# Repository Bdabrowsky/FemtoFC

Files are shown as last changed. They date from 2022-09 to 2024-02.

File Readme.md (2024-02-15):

# Hardware files for Open Source flight computer for small diameter rockets
## 17,5x50mm 
## For software, visit [Source Page]([https://github.com/Bdabrowsky/Clockwork_Banana](https://github.com/Bdabrowsky/Clockwork_Banana/tree/Clockwork_Banana_FemtoFC))
## All above hardware is made using funding from [Odkrywcy Diamentów](https://odkrywcydiamentow.com.pl/) grant program


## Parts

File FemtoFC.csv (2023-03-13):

Source: | C:\Users\Bdabrowski\Documents\GitHub\FemtoFC\FemtoFC.kicad_sch
Date: | 29.11.2022 20:14:57
Tool: | Eeschema (6.0.1)
Generator: | C:\Program Files\KiCad\6.0\bin\scripting\plugins/bom_csv_grouped_by_value_with_fp.py
Component Count: | 63
Ref | Qnty | Value | Cmp name | Footprint | Description | Vendor
BZ1, | 1 | Buzzer | Buzzer | Buzzer_Beeper:Buzzer_Murata_PKMCS0909E | Buzzer, polarized
C1, C4, C6, C7, C8, C9, C10, C13, | 8 | 100nF | C | Capacitor_SMD:C_0603_1608Metric_Pad1.08x0.95mm_HandSolder | Unpolarized capacitor
C2, C3, C5, | 3 | 10uF | C | Capacitor_SMD:C_0603_1608Metric_Pad1.08x0.95mm_HandSolder | Unpolarized capacitor
C11, C12, | 2 | 22pF | C | Capacitor_SMD:C_0603_1608Metric_Pad1.08x0.95mm_HandSolder | Unpolarized capacitor
D1, D2, | 2 | G | LED | LED_SMD:LED_0603_1608Metric | Light emitting diode
D3, D4, | 2 | D_Schottky | D_Schottky | Diode_SMD:D_SOD-123 | Schottky diode
D5, D6, | 2 | LED | LED | LED_SMD:LED_0603_1608Metric_Pad1.05x0.95mm_HandSolder | Light emitting diode
F1, F2, | 2 | Polyfuse | Polyfuse | Fuse:Fuse_1206_3216Metric_Pad1.42x1.75mm_HandSolder | Resettable fuse, polymeric positive temperature coefficient
FB1, | 1 | FerriteBead_Small | FerriteBead_Small | Resistor_SMD:R_0805_2012Metric | Ferrite bead, small symbol
J1, | 1 | Power in | Screw_Terminal_01x02 | Connector_PinHeader_2.54mm:PinHeader_1x02_P2.54mm_Vertical | Generic screw terminal, single row, 01x02, script generated (kicad-library-utils/schlib/autogen/connector/)
J2, | 1 | Conn_01x02_Male | Conn_01x02_Male | Connector_PinHeader_2.54mm:PinHeader_1x02_P2.54mm_Vertical | Generic connector, single row, 01x02, script generated (kicad-library-utils/schlib/autogen/connector/)
J3, | 1 | Micro_SD_Card | Micro_SD_Card | Connector_Card:microSD_HC_Molex_104031-0811 | Micro SD Card Socket
J4, | 1 | Pyro 2 | Screw_Terminal_01x02 | TerminalBlock_4Ucon:TerminalBlock_4Ucon_1x02_P3.50mm_Vertical | Generic screw terminal, single row, 01x02, script generated (kicad-library-utils/schlib/autogen/connector/)
J5, | 1 | Pyro 1 | Screw_Terminal_01x02 | TerminalBlock_4Ucon:TerminalBlock_4Ucon_1x02_P3.50mm_Vertical | Generic screw terminal, single row, 01x02, script generated (kicad-library-utils/schlib/autogen/connector/)
JP1, | 1 | SolderJumper_2_Open | SolderJumper_2_Open | Jumper:SolderJumper-2_P1.3mm_Open_RoundedPad1.0x1.5mm | Solder Jumper, 2-pole, open
JP2, | 1 | SolderJumper_3_Open | SolderJumper_3_Open | Jumper:SolderJumper-3_P1.3mm_Open_RoundedPad1.0x1.5mm | Solder Jumper, 3-pole, open
P1, | 1 | USB_C_Plug_USB2.0 | USB_C_Plug_USB2.0 | Connector_USB:USB_C_Receptacle_JAE_DX07S016JA1R1500 | USB 2.0-only Type-C Plug connector
Q1, | 1 | FDS9926A | FDS9926A | Package_SO:SOIC-8_3.9x4.9mm_P1.27mm | 6.5A Id, 20V Vds, Dual N-Channel MOSFET, 30mOhm Ron, SO-8
Q2, | 1 | FDS4953 | FDS4953 | Package_SO:SOIC-8_3.9x4.9mm_P1.27mm
Q3, | 1 | NDT3055L | NDT3055L | Package_TO_SOT_SMD:TSOT-23_HandSoldering | 4A Id, 60V Vds, N-Channel Logic Level Enhancement Mode MOSFET, SOT-223
R1, | 1 | 22k | R | Resistor_SMD:R_0603_1608Metric_Pad0.98x0.95mm_HandSolder | Resistor
R2, R6, R10, R11, R12, R13, R16, R17, | 8 | 10k | R | Resistor_SMD:R_0603_1608Metric_Pad0.98x0.95mm_HandSolder | Resistor
R3, R4, R5, R7, R8, R9, R14, R15, | 8 | 100k | R | Resistor_SMD:R_0603_1608Metric_Pad0.98x0.95mm_HandSolder | Resistor
TP1, TP2, TP3, TP4, TP5, | 5 | TestPoint | TestPoint | TestPoint:TestPoint_Pad_D1.0mm | test point
U1, | 1 | USBLC6-2SC6 | USBLC6-2SC6 | Package_TO_SOT_SMD:SOT-23-6 | Very low capacitance ESD protection diode, 2 data-line, SOT-23-6
U2, | 1 | 3.3v REG | AMS1117-3.3 | Package_TO_SOT_SMD:SOT-223-3_TabPin2 | 1A Low Dropout regulator, positive, 3.3V fixed output, SOT-223
U3, | 1 | ATSAMD21G18A-M | ATSAMD21G18A-M | Package_DFN_QFN:QFN-48-1EP_7x7mm_P0.5mm_EP5.15x5.15mm | SAM D21 Microchip SMART ARM-based Flash MCU, 48Mhz, 256K Flash, 32K SRAM, QFN-48
U4, | 1 | W25Q128JVS | W25Q128JVS | Package_SON:WSON-8-1EP_6x5mm_P1.27mm_EP3.4x4.3mm | 128Mb Serial Flash Memory, Standard/Dual/Quad SPI, SOIC-8
U5, | 1 | LSM6DS3 | LSM6DS3 | Package_LGA:LGA-14_3x2.5mm_P0.5mm_LayoutBorder3x4y | I2C/SPI, iNEMO inertial module: always-on 3D accelerometer and 3D gyroscope
U6, | 1 | BMP280 | BMP280 | Package_LGA:Bosch_LGA-8_2x2.5mm_P0.65mm_ClockwisePinNumbering | Absolute Barometric Pressure Sensor, LGA-8
Y1, | 1 | Crystal | Crystal | Crystal:Crystal_SMD_3215-2Pin_3.2x1.5mm | Two pin crystal

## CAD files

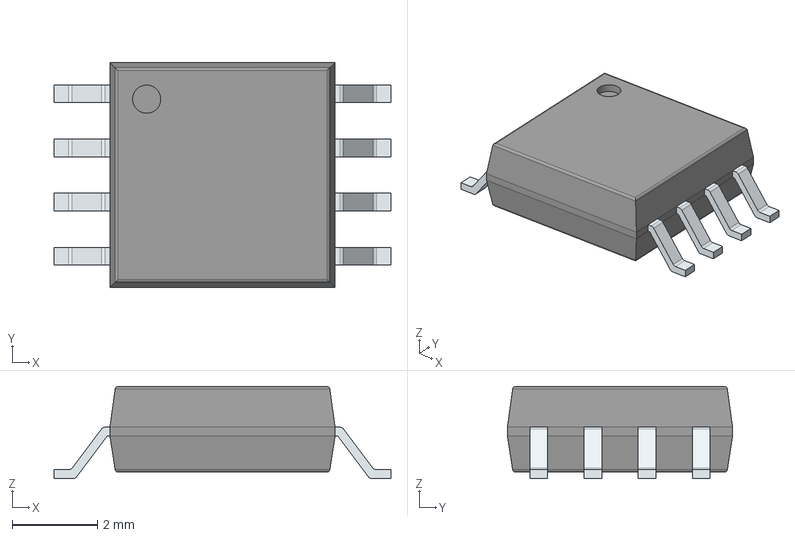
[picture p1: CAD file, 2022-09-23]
3D models/W25Q128JVSIM.stp
7.90 x 5.28 x 2.16 mm
PinsArrayLR

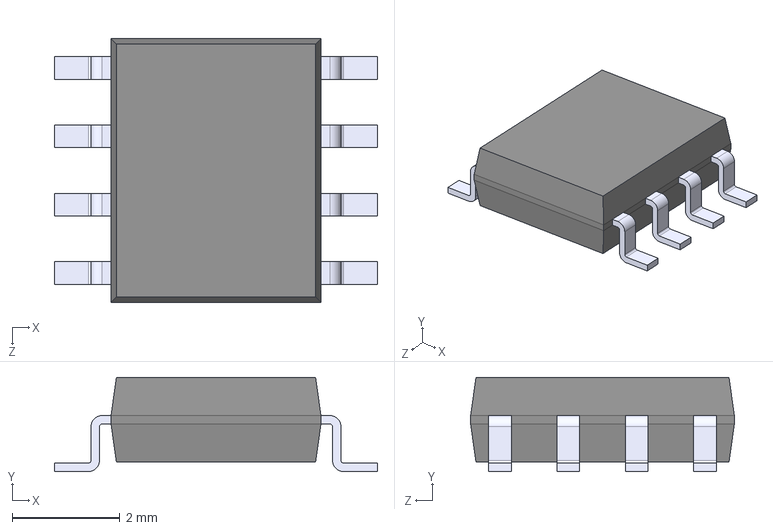
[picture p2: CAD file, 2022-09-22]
FDS4953/FDS4953.step
6.00 x 1.75 x 4.90 mm

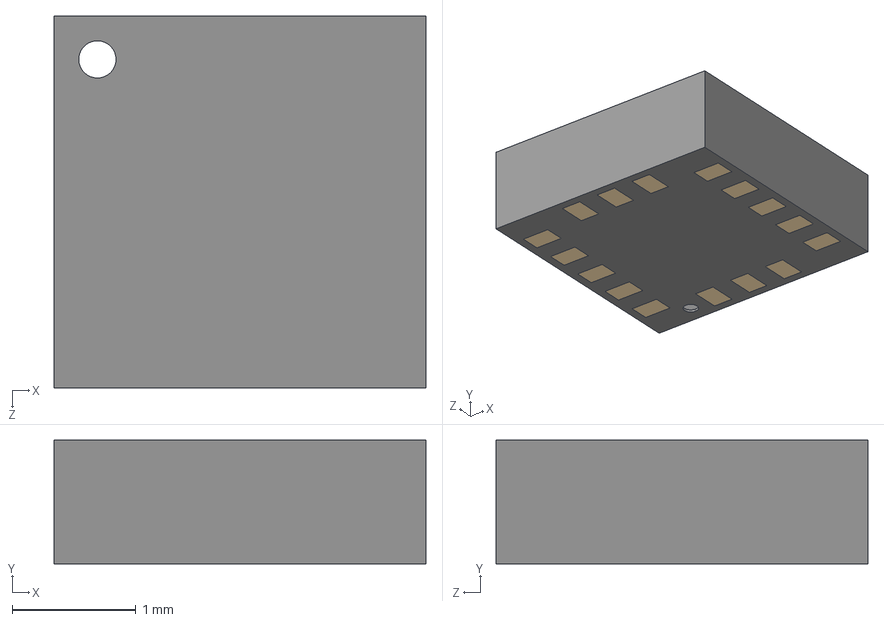
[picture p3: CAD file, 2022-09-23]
3D models/LSM6DS0.STEP
3.00 x 1.00 x 3.00 mm

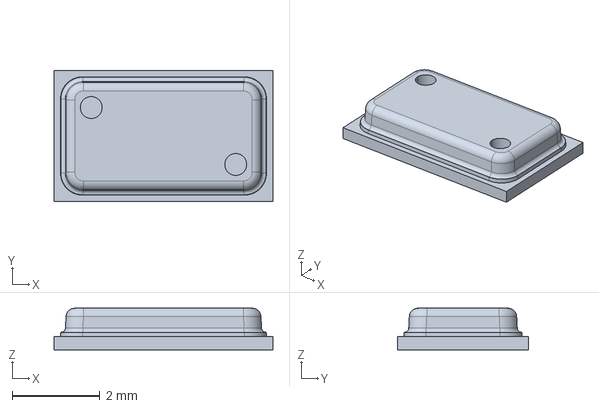
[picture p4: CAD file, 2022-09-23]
3D models/MS560702BA03-50.step
5.00 x 3.00 x 0.95 mm

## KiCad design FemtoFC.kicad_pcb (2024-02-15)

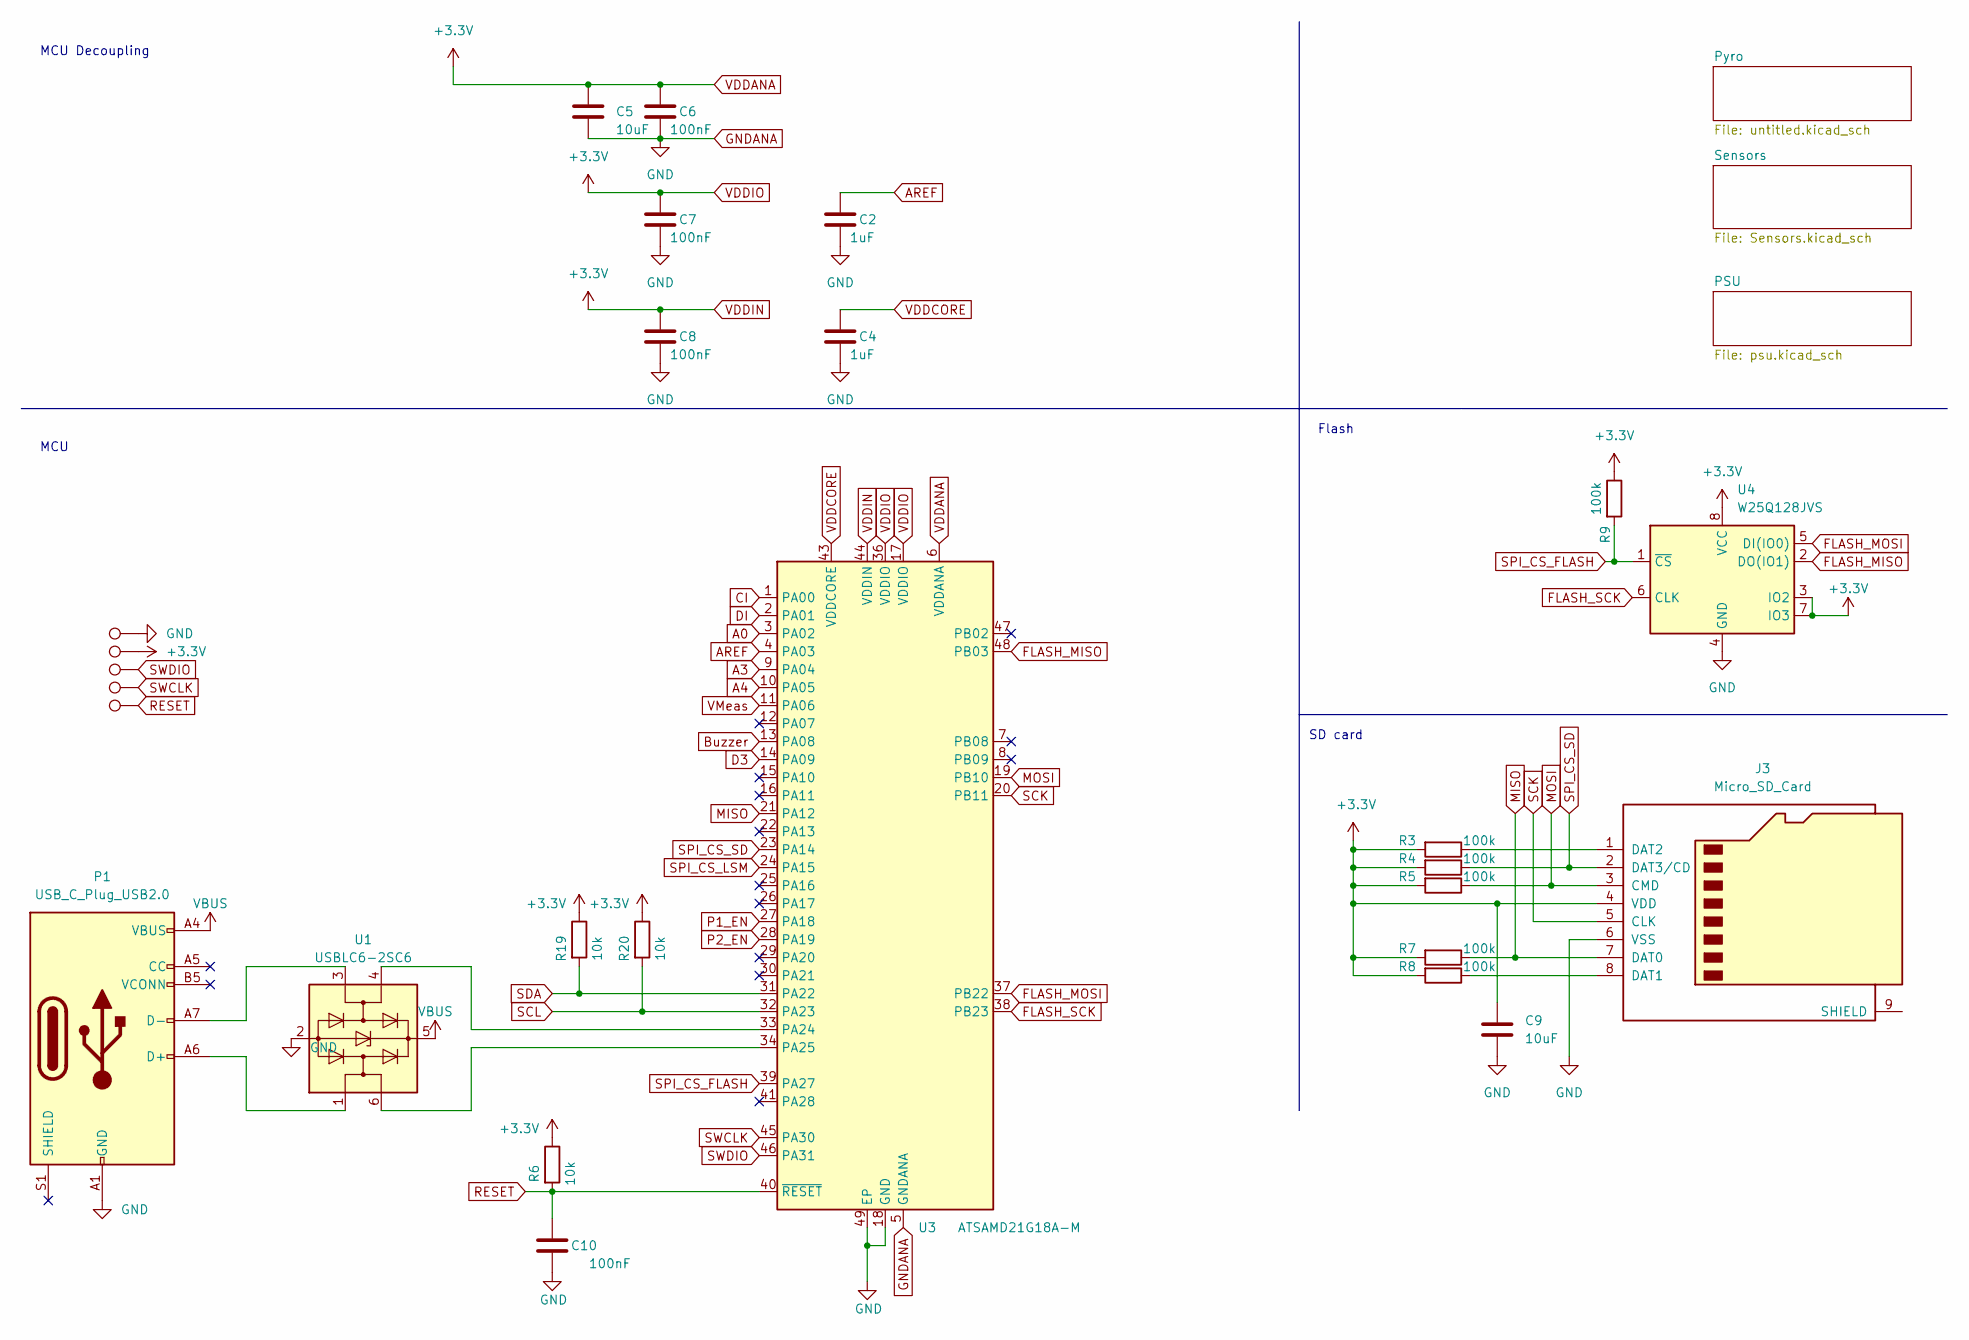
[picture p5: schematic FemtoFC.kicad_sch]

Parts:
C2, C4: 1uF; C_0402_1005Metric_Pad0.74x0.62mm_HandSolder
C5, C9: 10uF; C_0402_1005Metric_Pad0.74x0.62mm_HandSolder
C6, C7, C8, C10: 100nF; C_0402_1005Metric_Pad0.74x0.62mm_HandSolder
J3: Micro_SD_Card; microSD_HC_Molex_104031-0811
P1: USB_C_Plug_USB2.0; USB_C_Receptacle_JAE_DX07S016JA1R1500
R3, R4, R5, R7, R8, R9: 100k; R_0402_1005Metric_Pad0.72x0.64mm_HandSolder
R6, R19, R20: 10k; R_0402_1005Metric_Pad0.72x0.64mm_HandSolder
TP1, TP2, TP3, TP4, TP5: TestPoint; TestPoint_Pad_D1.0mm
U1: USBLC6-2SC6; SOT-23-6
U3: ATSAMD21G18A-M; QFN-48-1EP_7x7mm_P0.5mm_EP5.15x5.15mm
U4: W25Q128JVS; WSON-8-1EP_6x5mm_P1.27mm_EP3.4x4.3mm

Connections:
A0: U3.3 (PA02)
A3: U3.9 (PA04)
A4: U3.10 (PA05)
AREF: C2.1, U3.4 (PA03)
Buzzer: U3.13 (PA08); also elsewhere on the board
CI: U3.1 (PA00); also elsewhere on the board
D3: U3.14 (PA09)
DI: U3.2 (PA01); also elsewhere on the board
FLASH_MISO: U3.48 (PB03), U4.2 (DO(IO1))
FLASH_MOSI: U3.37 (PB22), U4.5 (DI(IO0))
FLASH_SCK: U3.38 (PB23), U4.6 (CLK)
GNDANA: C2.2, C4.2, C5.2, C6.2, C7.2, C8.2, C9.2, C10.2, J3.6 (VSS), P1.A1 (GND), P1.A12 (GND), P1.B1 (GND), P1.B12 (GND), TP1.1, U1.2 (GND), U3.5 (GNDANA), U3.18 (GND), U3.35 (GND), U3.42 (GND), U3.49 (EP), U4.4 (GND); also elsewhere on the board
MISO: J3.7 (DAT0), R7.1, U3.21 (PA12); also elsewhere on the board
MOSI: J3.3 (CMD), R5.1, U3.19 (PB10); also elsewhere on the board
unnamed: J3.1 (DAT2), R3.1
unnamed: J3.8 (DAT1), R8.1
unnamed: P1.A6 (D+), U1.1 (I/O1)
unnamed: P1.A7 (D-), U1.3 (I/O2)
unnamed: U1.4 (I/O2), U3.33 (PA24)
unnamed: U1.6 (I/O1), U3.34 (PA25)
P1_EN: U3.27 (PA18); also elsewhere on the board
P2_EN: U3.28 (PA19); also elsewhere on the board
RESET: C10.1, R6.2, TP5.1, U3.40 (~RESET)
SCK: J3.5 (CLK), U3.20 (PB11); also elsewhere on the board
SCL: R20.2, U3.32 (PA23); also elsewhere on the board
SDA: R19.2, U3.31 (PA22); also elsewhere on the board
SPI_CS_FLASH: R9.2, U3.39 (PA27), U4.1 (~CS)
SPI_CS_LSM: U3.24 (PA15); also elsewhere on the board
SPI_CS_SD: J3.2 (DAT3/CD), R4.1, U3.23 (PA14)
SWCLK: TP4.1, U3.45 (PA30)
SWDIO: TP3.1, U3.46 (PA31)
VBUS: P1.A4 (VBUS), P1.A9 (VBUS), P1.B4 (VBUS), P1.B9 (VBUS), U1.5 (VBUS); also elsewhere on the board
VDDANA: C5.1, C6.1, C7.1, C8.1, C9.1, J3.4 (VDD), R3.2, R4.2, R5.2, R6.1, R7.2, R8.2, R9.1, R19.1, R20.1, TP2.1, U3.6 (VDDANA), U3.17 (VDDIO), U3.36 (VDDIO), U3.44 (VDDIN), U4.3 (IO2), U4.7 (IO3), U4.8 (VCC); also elsewhere on the board
VDDCORE: C4.1, U3.43 (VDDCORE)
VMeas: U3.11 (PA06)

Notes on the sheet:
SD card
MCU
Flash
MCU Decoupling

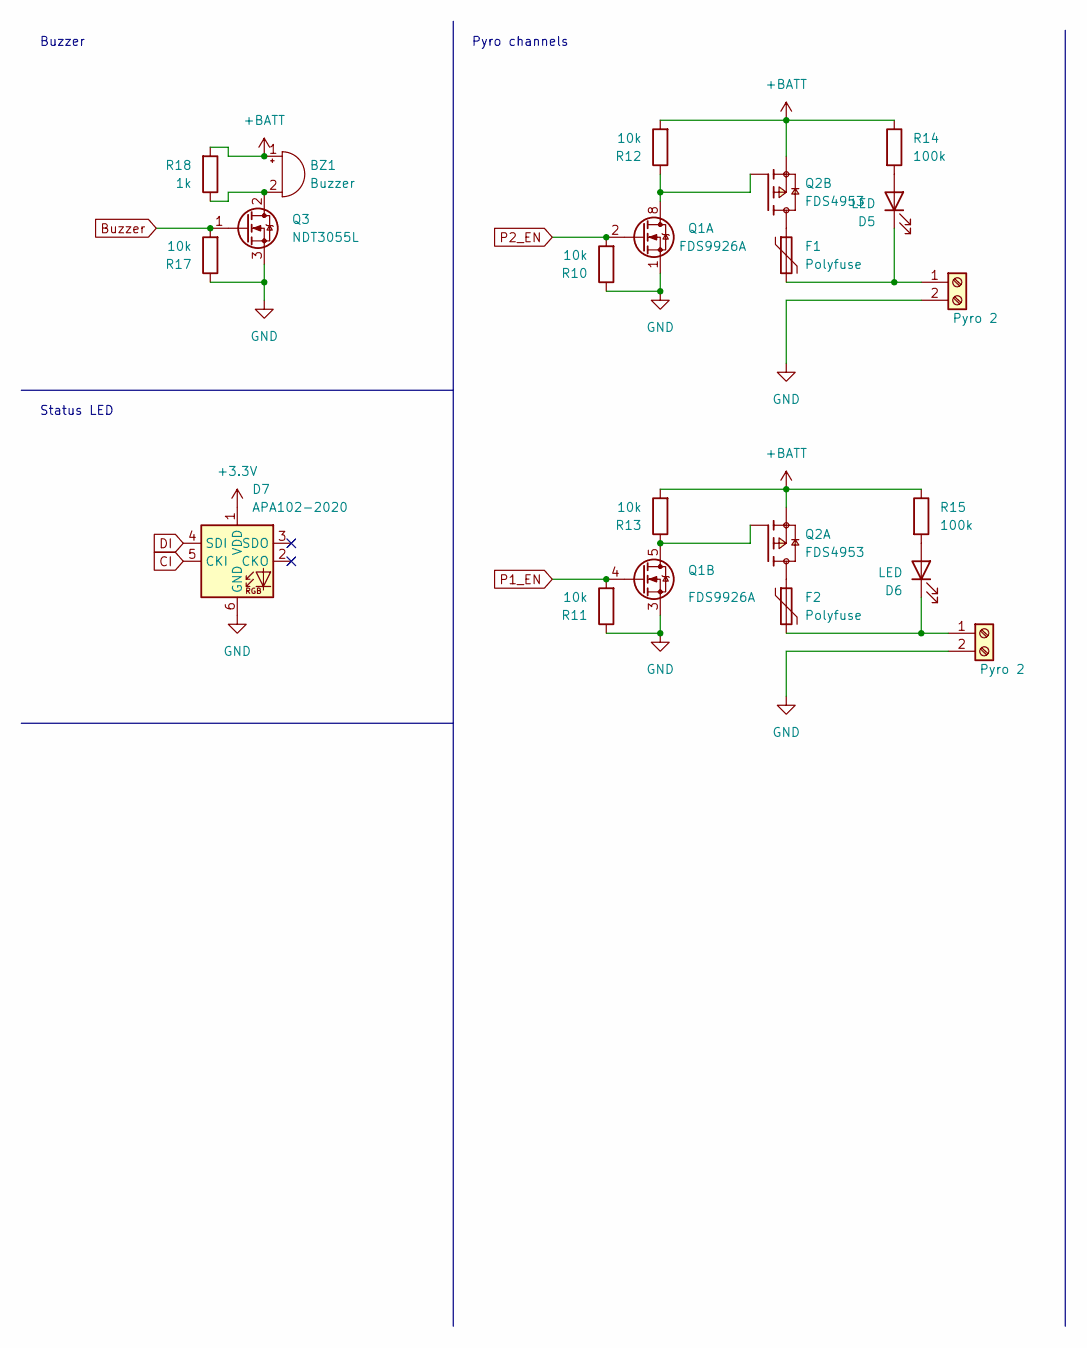
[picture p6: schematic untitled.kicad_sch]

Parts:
BZ1: Buzzer; Buzzer_Murata_PKMCS0909E
D5, D6: LED; LED_0603_1608Metric_Pad1.05x0.95mm_HandSolder
D7: APA102-2020; LED-APA102-2020
F1, F2: Polyfuse; Fuse_1206_3216Metric_Pad1.42x1.75mm_HandSolder
J4, J5: Pyro 2; TerminalBlock_Phoenix_MPT-0,5-2-2.54_1x02_P2.54mm_Horizontal
Q1: FDS9926A; SOIC-8_3.9x4.9mm_P1.27mm
Q2: FDS4953; SOIC-8_3.9x4.9mm_P1.27mm
Q3: NDT3055L; TSOT-23
R10, R11, R12, R13, R17: 10k; R_0402_1005Metric_Pad0.72x0.64mm_HandSolder
R14, R15: 100k; R_0402_1005Metric_Pad0.72x0.64mm_HandSolder
R18: 1k; R_0402_1005Metric_Pad0.72x0.64mm_HandSolder

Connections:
+BATT: BZ1.1 (-), Q2.1, Q2.3, R12.2, R13.2, R14.1, R15.1, R18.2; also elsewhere on the board
Buzzer: Q3.1 (G), R17.2; also elsewhere on the board
CI: D7.5 (CKI); also elsewhere on the board
DI: D7.4 (SDI); also elsewhere on the board
GNDANA: D7.6 (GND), J4.2, J5.2, Q1.1 (S1), Q1.3 (S2), Q3.3 (S), R10.1, R11.1, R17.1; also elsewhere on the board
unnamed: BZ1.2 (+), Q3.2 (D), R18.1
unnamed: D5.1 (K), F1.2, J4.1
unnamed: D5.2 (A), R14.2
unnamed: D6.1 (K), F2.2, J5.1
unnamed: D6.2 (A), R15.2
unnamed: F1.1, Q2.7, Q2.8
unnamed: F2.1, Q2.5, Q2.6
unnamed: Q1.5 (D2), Q1.6 (D2), Q2.4, R13.1
unnamed: Q1.7 (D1), Q1.8 (D1), Q2.2, R12.1
P1_EN: Q1.4 (G2), R11.2; also elsewhere on the board
P2_EN: Q1.2 (G1), R10.2; also elsewhere on the board
VDDANA: D7.1 (VDD); also elsewhere on the board

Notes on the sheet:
Buzzer
Status LED
Pyro channels

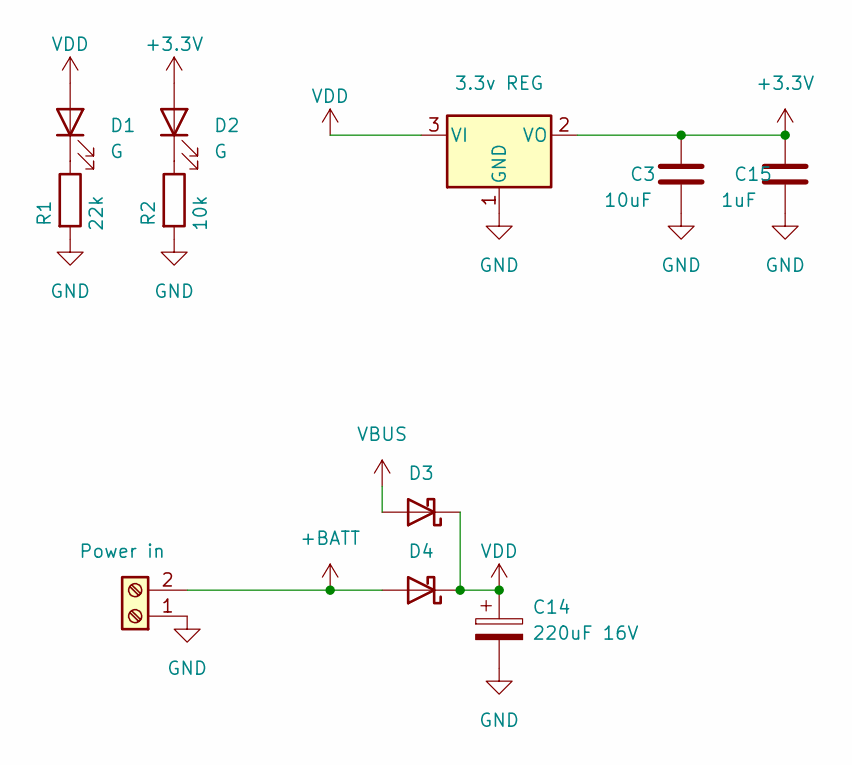
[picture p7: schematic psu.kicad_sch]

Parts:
C3: 10uF; C_0402_1005Metric_Pad0.74x0.62mm_HandSolder
C14: 220uF 16V; CP_EIA-7343-31_Kemet-D
C15: 1uF; C_0402_1005Metric_Pad0.74x0.62mm_HandSolder
D1, D2: G; LED_0603_1608Metric
D3, D4: D_Schottky; D_SOD-123
J1: Power in; PinHeader_1x02_P2.54mm_Vertical
R1: 22k; R_0402_1005Metric_Pad0.72x0.64mm_HandSolder
R2: 10k; R_0402_1005Metric_Pad0.72x0.64mm_HandSolder
U2: 3.3v REG; SOT-223-3_TabPin2

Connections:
+BATT: D4.2 (A), J1.2; also elsewhere on the board
GNDANA: C3.2, C14.2, C15.2, J1.1, R1.2, R2.2, U2.1 (GND); also elsewhere on the board
unnamed: D1.1 (K), R1.1
unnamed: D2.1 (K), R2.1
VBUS: D3.2 (A); also elsewhere on the board
VDD: C14.1, D1.2 (A), D3.1 (K), D4.1 (K), U2.3 (VI)
VDDANA: C3.1, C15.1, D2.2 (A), U2.2 (VO); also elsewhere on the board

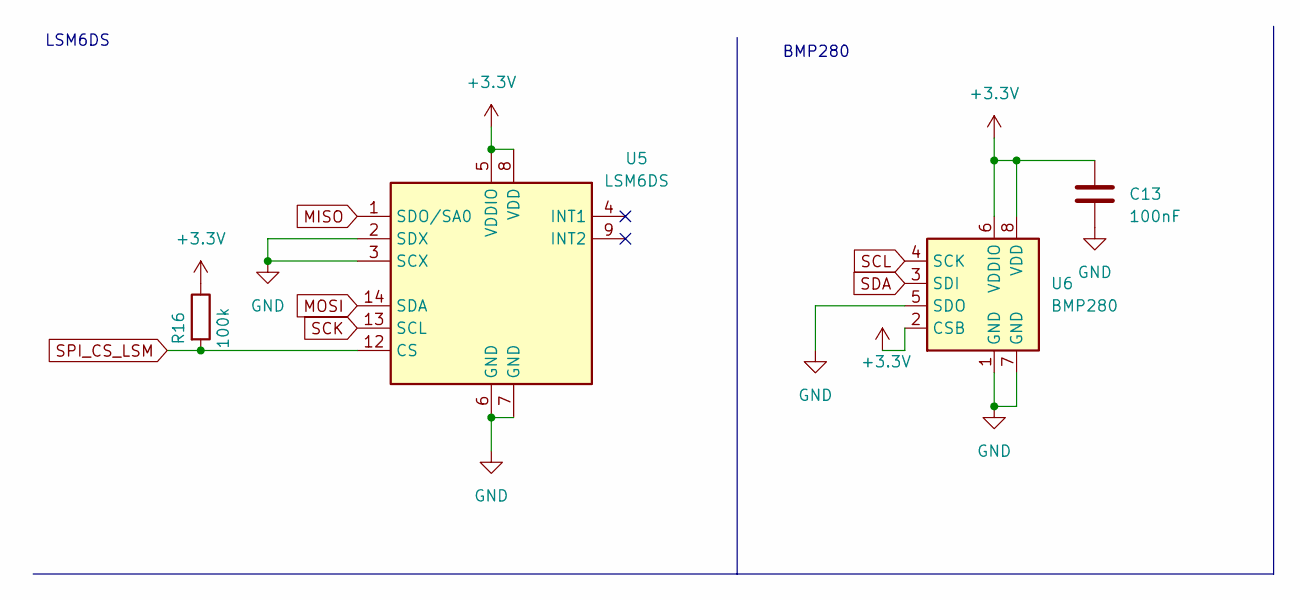
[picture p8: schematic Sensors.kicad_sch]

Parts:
C13: 100nF; C_0402_1005Metric_Pad0.74x0.62mm_HandSolder
R16: 100k; R_0402_1005Metric_Pad0.72x0.64mm_HandSolder
U5: LSM6DS; LGA-14_3x2.5mm_P0.5mm_LayoutBorder3x4y
U6: BMP280; Bosch_LGA-8_2x2.5mm_P0.65mm_ClockwisePinNumbering

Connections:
GNDANA: C13.2, U5.2 (SDX), U5.3 (SCX), U5.6 (GND), U5.7 (GND), U6.1 (GND), U6.5 (SDO), U6.7 (GND); also elsewhere on the board
MISO: U5.1 (SDO/SA0); also elsewhere on the board
MOSI: U5.14 (SDA); also elsewhere on the board
SCK: U5.13 (SCL); also elsewhere on the board
SCL: U6.4 (SCK); also elsewhere on the board
SDA: U6.3 (SDI); also elsewhere on the board
SPI_CS_LSM: R16.2, U5.12 (CS); also elsewhere on the board
VDDANA: C13.1, R16.1, U5.5 (VDDIO), U5.8 (VDD), U6.2 (CSB), U6.6 (VDDIO), U6.8 (VDD); also elsewhere on the board

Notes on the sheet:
BMP280
LSM6DS

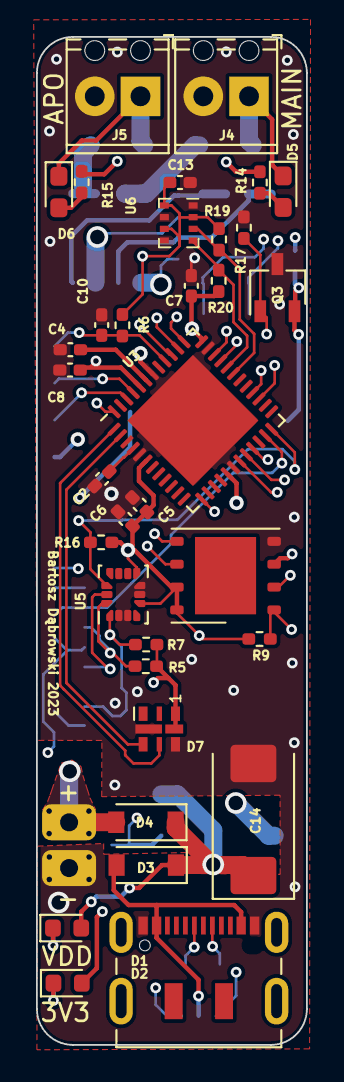
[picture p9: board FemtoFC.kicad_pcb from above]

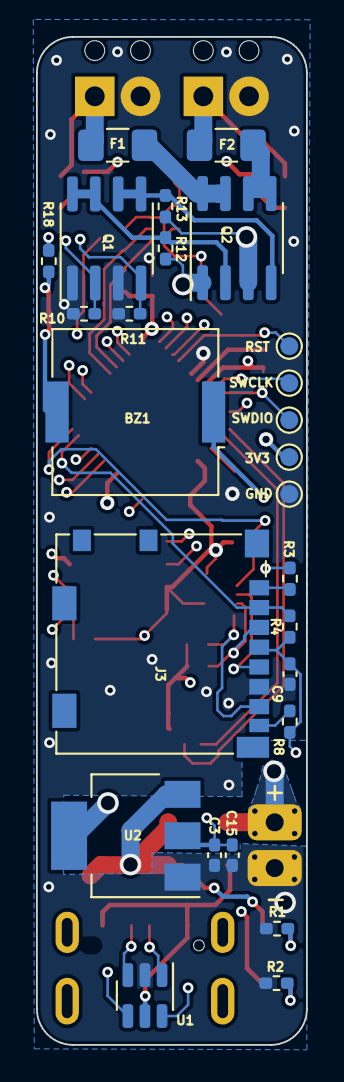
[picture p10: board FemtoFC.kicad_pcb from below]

Board: 4 copper layers, 15.0 x 56.0 mm, 61 parts (26 on the bottom side), 43 nets.

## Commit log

2022-09-23 0.2
    PCB edit
    Added 3D models
    [FemtoFC.kicad_pcb, FemtoFC.kicad_sch, LSM6DS0.STEP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]
2023-03-13 Rework for prototype 2
    [FemtoFC.csv, FemtoFC.kicad_pcb, FemtoFC.kicad_sch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]
2023-05-27 Rev 27052023
    [FemtoFC.kicad_pcb, FemtoFC.kicad_sch, Sensors.kicad_sch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]
2023-06-18 fixed ground short
    [FemtoFC.kicad_pcb, FemtoFC.kicad_sch, psu.kicad_sch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]
2023-12-02 Shortcircuit fix, maybe final version before rev2
    [FemtoFC.kicad_pcb, FemtoFC.kicad_sch, Sensors.kicad_sch]
2024-02-15 Removed a bunch of DRC warnings
    [FemtoFC.kicad_pcb]
